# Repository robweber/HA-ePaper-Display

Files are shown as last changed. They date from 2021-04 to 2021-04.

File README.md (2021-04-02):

# HA Sensor ePaper Display
__Modified for robweber__

E-Paper display for viewing sensor data from Home Assistant. This firmware is based on **ESPhome**, so you need to install ESPhome and compile .yaml file by yourself.

header

## Sensors data 

N/A

## Hardware

hw

### Parts:
 1. Waveshare 4.2" ePaper display
 2. ESP8266 Wemos D1 Mini or similiar. I used NodeMCU ESP8266
 3. 3D-Printed Case, it can be found on my thingiverse page. [https://www.thingiverse.com/thing:4772803]
 4. Stock M3 Screws from ePaper display

Note: You might need to apply some adhesives to 3d-printed parts joints, and also put some counterweight on the base to make it harder to tip over. This is my very first time designing 3D things, so it’s not perfect yet.
 
 ### Wiring: 
Connecting the display to Wemos D1 Mini is very straightforward. However, I soldered all wires diretly on both display and MCU in order to make it low-profile as much as possible. Refer to the ESP8266 pinout reference in the images folder if having trouble. 

|ePaper Display Pin| ESP8266 Pin|
|--|--|
| BUSY | GPIO16 |
| RST | GPIO04  |
| DC | GPIO12 |
| CS | GPIO15 |
| CLK | GPIO14 |
| DIN | GPIO13 |
| GND | GND |
| 3.3v | 3.3v |

## How to use?

 1. Install ESPhome on your [computer](https://esphome.io/guides/getting_started_command_line.html) or [Home Assistant Add-on](https://esphome.io/guides/getting_started_hassio.html)
 2. Copy yaml file and fonts folder to your ESPhome folder. __Note__: The fonts must be in the root ESPhome folder, not the project folder. 
 3. Use ESPHome to make a new device and set the basics (Wifi SSID, name, etc). Compile and Upload this to your device. 
 4. Confirm device can talk with ESPHome. 
 5. Connect hardwares together.
 6. Flash firmware with full yml config. 
 7. Confirm you can see everything in ESPHome. 
 8. Enjoy!

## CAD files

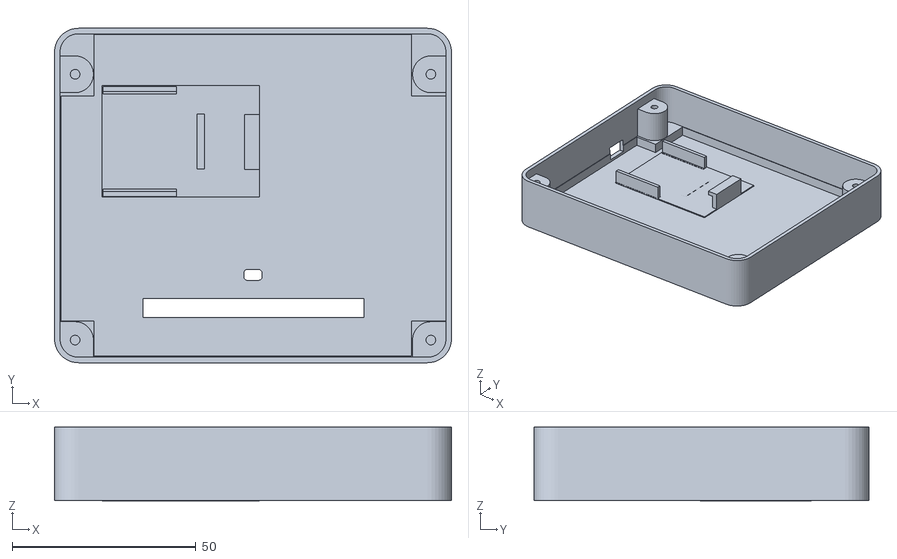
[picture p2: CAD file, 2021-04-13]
case/bottom_frame_nodemcu.stl
108.0 x 91.0 x 20.0

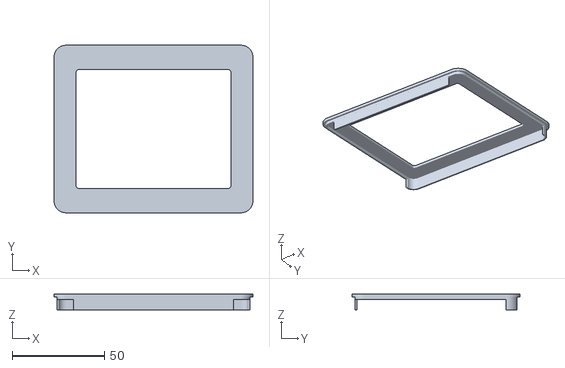
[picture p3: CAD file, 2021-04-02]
case/top_frame.stl
108.0 x 91.0 x 8.50

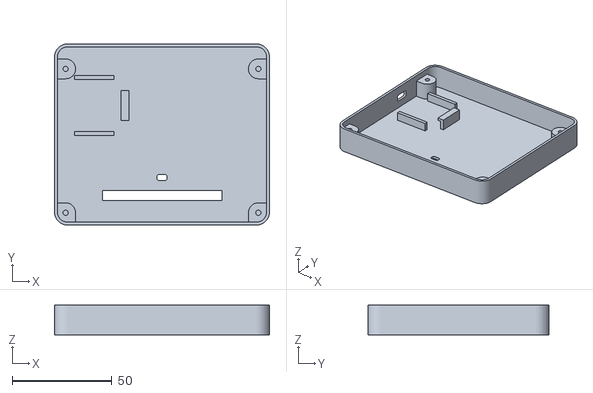
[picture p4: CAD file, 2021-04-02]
case/bottom_frame.stl
108.0 x 91.0 x 15.0

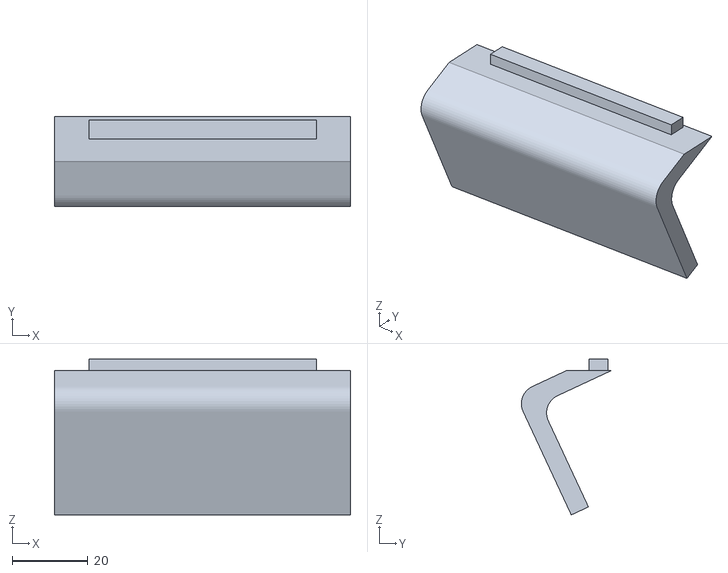
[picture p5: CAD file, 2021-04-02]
case/stand.stl
78.0 x 23.8 x 41.1

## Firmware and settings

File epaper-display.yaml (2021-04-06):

esphome:
  name: bedside_display
  platform: ESP8266
  board: nodemcuv2
  on_boot:
    priority: -10
    then:
      - delay: 20s
      - component.update: epaperdisplay

wifi:
  ssid: ""
  password: ""

  # Enable fallback hotspot (captive portal) in case wifi connection fails
  ap:
    ssid: "Bedside Display Fallback Hotspot"
    password: ""

captive_portal:

# Enable logging
logger:

# Enable Home Assistant API
api:
  password: ""

ota:
  password: ""

# get time from home assistant
time:
  - platform: homeassistant
    id: homeassistant_time

# list of sensors
sensor:
  # the wifi signal of the board
  - platform: wifi_signal
    name: 'Wifi Signal Sensor'
    id: wifisignal
    update_interval: 60s
    
  - platform: homeassistant
    entity_id: sensor.thermostat_temperature
    id: thermostat_temp
    
  - platform: homeassistant
    entity_id: sensor.weather_current_temp
    id: outside_temp
    
  - platform: homeassistant
    entity_id: sensor.daily_energy
    id: daily_energy

text_sensor:
  # the next alarm on your phone
  - platform: homeassistant
    entity_id: sensor.rob_next_alarm_time
    id: next_alarm

# list of binary sensors
binary_sensor:
  - platform: homeassistant
    entity_id: binary_sensor.house_secure
    id: house_secure
    on_state:
      then:
        - component.update: epaperdisplay  # update the display when this changes

# load fonts to use - for material icons use hex code
font:
  - file: 'fonts/Roboto-Regular.ttf'
    id: roboto_reg_15
    size: 15
    glyphs:
      ['&', '@', '!', ',', '.', '"', '%', '(', ')', '+', '-', '_', ':', '°', '0',
       '1', '2', '3', '4', '5', '6', '7', '8', '9', 'A', 'B', 'C', 'D', 'E',
       'F', 'G', 'H', 'I', 'J', 'K', 'L', 'M', 'N', 'O', 'P', 'Q', 'R', 'S',
       'T', 'U', 'V', 'W', 'X', 'Y', 'Z', ' ', 'a', 'b', 'c', 'd', 'e', 'f',
       'g', 'h', 'i', 'j', 'k', 'l', 'm', 'n', 'o', 'p', 'q', 'r', 's', 't',
       'u', 'v', 'w', 'x', 'y', 'z','å', 'ä', 'ö', '/','º','µ','³']

  - file: 'fonts/Roboto-Regular.ttf'
    id: roboto_reg_20
    size: 20
    glyphs:
      ['&', '@', '!', ',', '.', '"', '%', '(', ')', '+', '-', '_', ':', '°', '0',
       '1', '2', '3', '4', '5', '6', '7', '8', '9', 'A', 'B', 'C', 'D', 'E',
       'F', 'G', 'H', 'I', 'J', 'K', 'L', 'M', 'N', 'O', 'P', 'Q', 'R', 'S',
       'T', 'U', 'V', 'W', 'X', 'Y', 'Z', ' ', 'a', 'b', 'c', 'd', 'e', 'f',
       'g', 'h', 'i', 'j', 'k', 'l', 'm', 'n', 'o', 'p', 'q', 'r', 's', 't',
       'u', 'v', 'w', 'x', 'y', 'z','å', 'ä', 'ö', '/','º','µ','³']
       
  - file: 'fonts/Roboto-Medium.ttf'
    id: roboto_med_30
    size: 30
    glyphs:
      ['&', '@', '!', ',', '.', '"', '%', '(', ')', '+', '-', '_', ':', '°', '0',
       '1', '2', '3', '4', '5', '6', '7', '8', '9', 'A', 'B', 'C', 'D', 'E',
       'F', 'G', 'H', 'I', 'J', 'K', 'L', 'M', 'N', 'O', 'P', 'Q', 'R', 'S',
       'T', 'U', 'V', 'W', 'X', 'Y', 'Z', ' ', 'a', 'b', 'c', 'd', 'e', 'f',
       'g', 'h', 'i', 'j', 'k', 'l', 'm', 'n', 'o', 'p', 'q', 'r', 's', 't',
       'u', 'v', 'w', 'x', 'y', 'z','å', 'ä', 'ö', '/','º','µ','³']
  
  - file: 'fonts/Roboto-Bold.ttf'
    id: roboto_bold_60
    size: 60
    glyphs:
      ['0', '1', '2', '3', '4', '5', '6', '7', '8', '9', '°']

  - file: 'fonts/materialdesignicons-webfont.ttf'
    id:  mdi_wifi
    size: 20
    glyphs: [
      # Wifi
      "\U000F092F", # mdi-wifi-strength-alert-outline
      "\U000F091F", # mdi-wifi-strength-1
      "\U000F0922", # mdi-wifi-strength-2
      "\U000F0925", # mdi-wifi-strength-3
      "\U000F0928", # mdi-wifi-strength-4
      "\U000F00ED", # mdi-calendar
      "\U000F050F" # mdi-thermometer
      ]

  - file: 'fonts/materialdesignicons-webfont.ttf'
    id:  mdi_large
    size: 80
    glyphs: [
      "\U000F033E", # mdi-lock
      "\U000F0FC6"  # mdi-lock-open-variant
      ]

spi:
  clk_pin: 14
  mosi_pin: 13  #DIN
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

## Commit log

2021-04-02 updated README.md and added pinout for NodeMCU board
2021-04-02 didn't need cad files
    [ePaper_42_frame.f3z]
2021-04-02 added STL files to keep everything in one spot
    [bottom_frame.stl, stand.stl, top_frame.stl]
2021-04-06 update display sensors for bedside table
2021-04-13 added modified frame for a nodemcu size board
    [bottom_frame_nodemcu.stl]
